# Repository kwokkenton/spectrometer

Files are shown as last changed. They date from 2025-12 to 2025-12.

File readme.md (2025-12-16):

# OpenJuice (OJ): Multispectral sensor spectrophotometer for fruit juice quality inspection

Sensor Technologies and Applications coursework 16/12/2025.

Kenton Kwok

## Installation

### Configuring the Arduino

1. Install Arduino IDE
2. Plug the Arduino into the computer via USB. Ensure that the Arduino IDE can find detect the Arduino device.
3. Ensure that SparkFun AS7343 Arduino Library is included using the Library Manager
4. Import and flash `spectrometer.ino` onto the device

This script (spectrometer.ino) is mainly based on an example script from SparkFun (see license) in the file.

### Running the main GUI

This has been tested on Python 3.13.2. The main function uses serial communications with the Arduino. Ensure that the serial monitor is off when running the Python GUI or else it won't run.

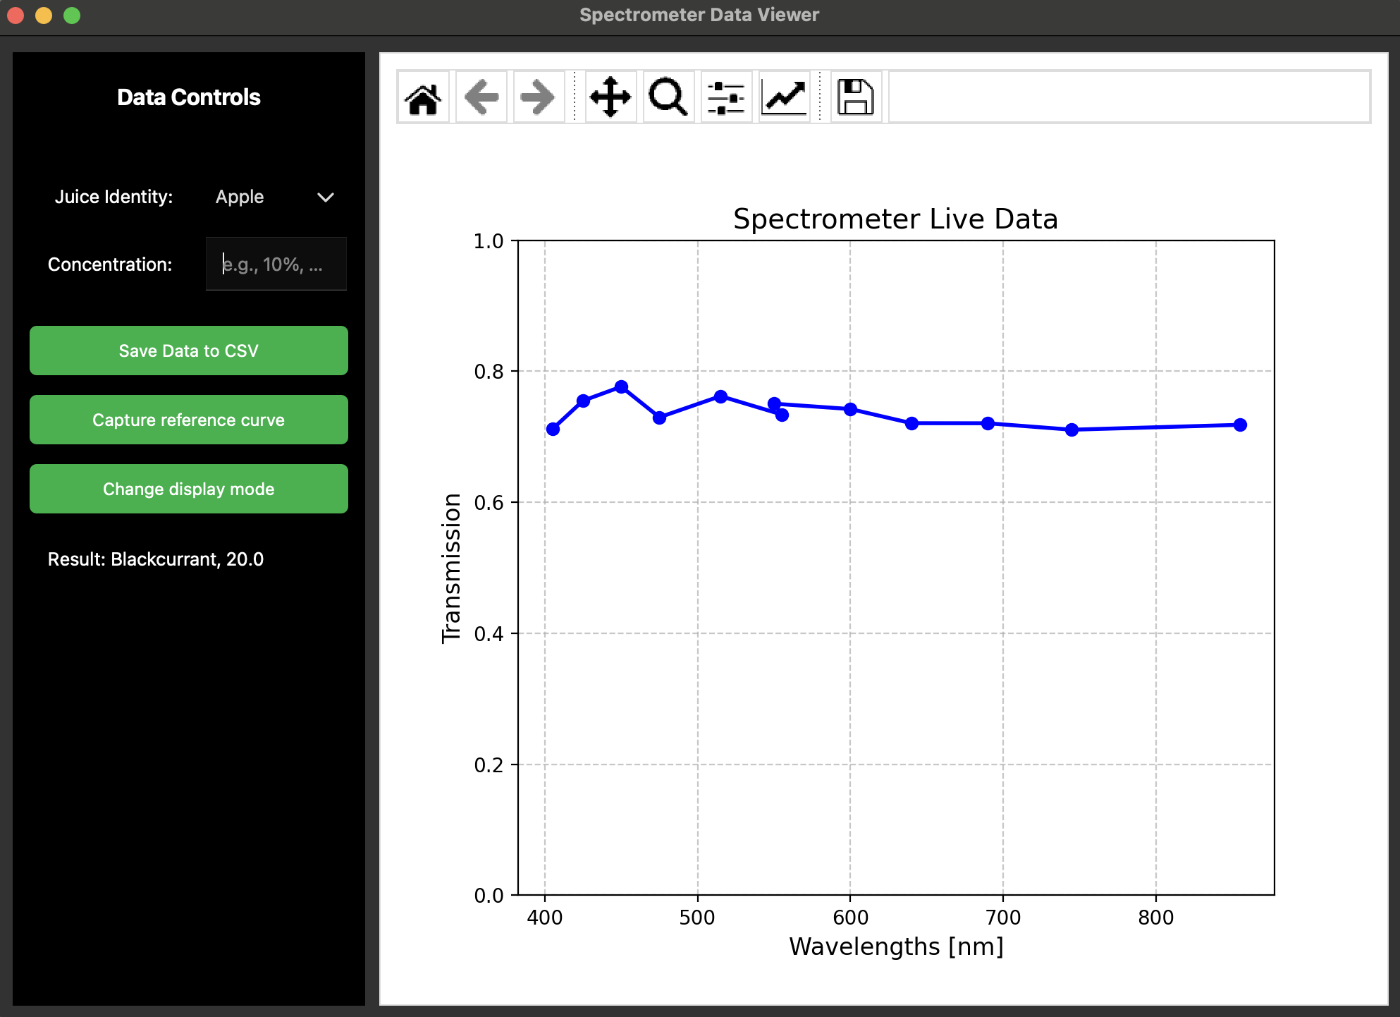
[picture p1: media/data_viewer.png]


```bash
# Installation
python3 -m venv venv
source venv/bin/activate
pip install -m requirements.txt
```

To run

```bash
python3 gui.py
```

### Creating figures

Figures are in `analysis.ipynb` for replication.

## Mechanical construction of 3D Model

Please follow construction instructions in the Appendix of the report.

## License

Copyright 2025 Kenton Kwok.

Permission is hereby granted, free of charge, to any person obtaining a copy of this software and associated documentation files (the “Software”), to deal in the Software without restriction, including without limitation the rights to use, copy, modify, merge, publish, distribute, sublicense, and/or sell copies of the Software, and to permit persons to whom the Software is furnished to do so, subject to the following conditions:

The above copyright notice and this permission notice shall be included in all copies or substantial portions of the Software.

THE SOFTWARE IS PROVIDED “AS IS”, WITHOUT WARRANTY OF ANY KIND, EXPRESS OR IMPLIED, INCLUDING BUT NOT LIMITED TO THE WARRANTIES OF MERCHANTABILITY, FITNESS FOR A PARTICULAR PURPOSE AND NONINFRINGEMENT. IN NO EVENT SHALL THE AUTHORS OR COPYRIGHT HOLDERS BE LIABLE FOR ANY CLAIM, DAMAGES OR OTHER LIABILITY, WHETHER IN AN ACTION OF CONTRACT, TORT OR OTHERWISE, ARISING FROM, OUT OF OR IN CONNECTION WITH THE SOFTWARE OR THE USE OR OTHER DEALINGS IN THE SOFTWARE.

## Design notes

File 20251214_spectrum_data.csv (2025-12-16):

F1 | F2 | FZ | F3 | F4 | F5 | FY | FXL | F6 | F7 | F8 | NIR | Juice | Concentration [%] | Timestamp
67 | 82 | 151 | 141 | 99 | 131 | 321 | 375 | 309 | 155 | 65 | 78 | Blackcurrant | 100 | 2025-12-14 10:59:36
187 | 267 | 635 | 521 | 404 | 407 | 781 | 677 | 451 | 273 | 163 | 202 | Blackcurrant | 20 | 2025-12-14 11:01:54
135 | 184 | 408 | 347 | 271 | 290 | 583 | 542 | 376 | 219 | 120 | 148 | Blackcurrant | 40 | 2025-12-14 11:02:47
97 | 129 | 266 | 230 | 174 | 202 | 438 | 446 | 330 | 181 | 89 | 110 | Blackcurrant | 60 | 2025-12-14 11:03:32
69 | 90 | 175 | 152 | 114 | 140 | 331 | 364 | 282 | 151 | 66 | 80 | Blackcurrant | 80 | 2025-12-14 11:04:13
63 | 88 | 235 | 213 | 196 | 175 | 376 | 322 | 199 | 113 | 57 | 70 | Orange | 10 | 2025-12-14 11:07:30
14 | 22 | 91 | 88 | 86 | 72 | 195 | 188 | 109 | 53 | 15 | 17 | Orange | 20 | 2025-12-14 11:08:15
1 | 4 | 23 | 23 | 35 | 27 | 89 | 85 | 48 | 21 | 2 | 2 | Orange | 40 | 2025-12-14 11:09:22
0 | 1 | 7 | 7 | 18 | 16 | 53 | 52 | 30 | 14 | 2 | 1 | Orange | 60 | 2025-12-14 11:10:12
0 | 1 | 3 | 4 | 13 | 12 | 41 | 42 | 25 | 11 | 1 | 1 | Orange | 80 | 2025-12-14 11:12:10
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

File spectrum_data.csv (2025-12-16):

F1 | F2 | FZ | F3 | F4 | F5 | FY | FXL | F6 | F7 | F8 | NIR | Juice | Concentration [%] | Timestamp
275 | 387 | 939 | 795 | 617 | 604 | 996 | 891 | 576 | 368 | 238 | 291 | Water | 100 | 2025-12-10 18:07:47
275 | 387 | 938 | 794 | 616 | 603 | 996 | 891 | 576 | 368 | 237 | 291 | Water | 100 | 2025-12-10 18:07:49
275 | 387 | 938 | 794 | 617 | 604 | 996 | 891 | 576 | 368 | 238 | 291 | Water | 100 | 2025-12-10 18:07:50
275 | 387 | 939 | 795 | 617 | 603 | 996 | 892 | 576 | 368 | 238 | 292 | Water | 100 | 2025-12-10 18:07:52
275 | 387 | 938 | 794 | 617 | 604 | 996 | 891 | 577 | 368 | 237 | 291 | Water | 100 | 2025-12-10 18:07:53
199 | 271 | 626 | 538 | 406 | 428 | 819 | 726 | 487 | 294 | 175 | 214 | Blackcurrant | 20 | 2025-12-10 18:15:01
199 | 271 | 626 | 540 | 406 | 428 | 820 | 726 | 488 | 294 | 175 | 214 | Blackcurrant | 20 | 2025-12-10 18:15:03
199 | 270 | 625 | 539 | 406 | 428 | 820 | 725 | 487 | 294 | 175 | 214 | Blackcurrant | 20 | 2025-12-10 18:15:05
199 | 270 | 624 | 537 | 406 | 427 | 819 | 723 | 487 | 294 | 175 | 214 | Blackcurrant | 20 | 2025-12-10 18:15:07
199 | 270 | 625 | 539 | 406 | 427 | 819 | 725 | 487 | 294 | 174 | 214 | Blackcurrant | 20 | 2025-12-10 18:15:08
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

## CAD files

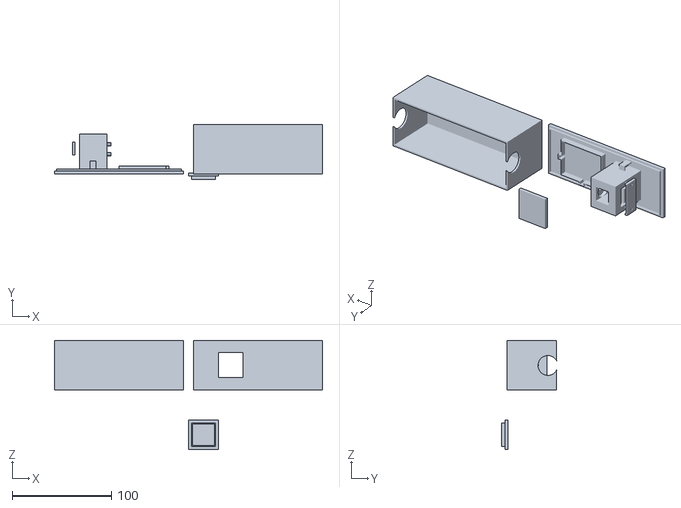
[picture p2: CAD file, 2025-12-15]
spectrometer.stl
270.0 x 55.9 x 110.0

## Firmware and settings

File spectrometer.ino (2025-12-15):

/*
  Using the AMS AS7343 Sensor.

  This example shows how to setup the AS7343 sensor with default settings and
  print out all the spectral data from the sensor.

  By: Pete Lewis
  SparkFun Electronics
  Date: 2025/04/22
  SparkFun code, firmware, and software is released under the MIT License.
    Please see LICENSE.md for further details.

  Hardware Connections:
  IoT RedBoard --> AS7331
  QWIIC --> QWIIC

  Serial.print it out at 115200 baud to serial monitor.

  Feel like supporting our work? Buy a board from SparkFun!
  https://www.sparkfun.com/products/23220
*/

#include <SparkFun_AS7343.h>

SfeAS7343ArdI2C mySensor;

uint16_t myData[ksfAS7343NumChannels]; // Array to hold spectral data
int pin = 9;

sfe_as7343_again_t gainSettings[] = {
    AGAIN_0_5,
    AGAIN_1,
    AGAIN_2,
    AGAIN_4,
    AGAIN_8,
    AGAIN_16,
    AGAIN_32,
    AGAIN_64,
    AGAIN_128,
    AGAIN_256,
    AGAIN_512,
    AGAIN_1024,
    AGAIN_2048};

// Variable to hold current user set gain index (position within the array)
int gainSettingIndex = 8; // default to 256x gain


void LEDSetup() 
{
    pinMode(pin, OUTPUT);           // set pin to input
    digitalWrite(pin, HIGH); 
}

void setup()
{   
    Serial.begin(115200);
    while (!Serial)
    {
        delay(100);
    };

    Wire.begin();

    // Initialize sensor and run default setup.
    if (mySensor.begin() == false)
    {
        Serial.println("Sensor failed to begin. Please check your wiring!");
        Serial.println("Halting...");
        while (1)
            ;
    }

    Serial.println("Sensor began.");

    // Power on the device
    if (mySensor.powerOn() == false)
    {
        Serial.println("Failed to power on the device.");
        Serial.println("Halting...");
        while (1)
            ;
    }
    Serial.println("Device powered on.");

    // Set the AutoSmux to output all 18 channels
    if (mySensor.setAutoSmux(AUTOSMUX_18_CHANNELS) == false)
    {
        Serial.println("Failed to set AutoSmux.");
        Serial.println("Halting...");
        while (1)
            ;
    }
    Serial.println("AutoSmux set to 18 channels.");

    // Enable Spectral Measurement
    if (mySensor.enableSpectralMeasurement() == false)
    {
        Serial.println("Failed to enable spectral measurement.");
        Serial.println("Halting...");
        while (1)
            ;
    }
    Serial.println("Spectral measurement enabled.");

    LEDSetup();

}

void loop()
{
    // mySensor.ledOn();
    // delay(100);

    // Read all data registers
    // if it fails, print a failure message and continue
    if (mySensor.readSpectraDataFromSensor() == false)
    {
        Serial.println("Failed to read spectral data.");
    }

    // mySensor.ledOff();

    char buffer[100];

    // fill buffer with the channel data in the correct order
    // The order is important, as the web terminal will use this order to display the bar graphs.
    // F1, F2, FZ, F3, F4, F5, FY, FXL, F6, F7, F8, VIS, NIR
    sprintf(buffer, "%d,%d,%d,%d,%d,%d,%d,%d,%d,%d,%d,%d\n",
           mySensor.getChannelData(CH_PURPLE_F1_405NM),
           mySensor.getChannelData(CH_DARK_BLUE_F2_425NM),
           mySensor.getChannelData(CH_BLUE_FZ_450NM),
           mySensor.getChannelData(CH_LIGHT_BLUE_F3_475NM),
           mySensor.getChannelData(CH_BLUE_F4_515NM),
           mySensor.getChannelData(CH_GREEN_F5_550NM),
           mySensor.getChannelData(CH_GREEN_FY_555NM),
           mySensor.getChannelData(CH_ORANGE_FXL_600NM),
           mySensor.getChannelData(CH_BROWN_F6_640NM),
           mySensor.getChannelData(CH_RED_F7_690NM),
           mySensor.getChannelData(CH_DARK_RED_F8_745NM),
        //    mySensor.getChannelData(CH_VIS_1),
           mySensor.getChannelData(CH_NIR_855NM));

    if (mySensor.setAgain(gainSettings[gainSettingIndex]) == false)
    {
        Serial.println("Failed to set gain.");
        return;
    }

    Serial.println(buffer);

    delay(500);
}

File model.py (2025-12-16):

import numpy as np
import pandas as pd
from scipy.interpolate import CubicSpline, interp1d

wavelengths_nm = np.array([405, 425, 450, 475, 515, 555, 550, 600, 640, 690, 745, 855])


class Database:
    def __init__(self, limit=0, limit_end = None):
        self.templates = []
        self.targets = []
        self.limit = limit
        self.limit_end = limit_end
    
    def add(self, x, y):
        self.templates.append(x)
        self.targets.append(y)
        return
    
    def search(self, x):
        x = x[self.limit:self.limit_end]
        return self.targets[np.argmin(np.linalg.norm(np.array(self.templates)[:,self.limit:self.limit_end]- x, axis=1))]
    
    def __len__(self):
        return len(self.targets)
    
def synthesise_absorbance(splines, c):
    return np.array([s(c) for s in splines])

def populate_db(juices, db, data, mode = 'spline'):
    for j in juices:
        splines = []
        for w in range(len(wavelengths_nm)):
            concs = data[j][0]
            pts = [i[w] for i in data[j][1]]
            if mode == 'spline':
                spline = CubicSpline(concs, pts)
            else:
                spline = interp1d(concs, pts)
            splines.append(spline)

        for idx, conc in enumerate(np.linspace(data[j][0].min(), data[j][0].max(), 21)):
            t = synthesise_absorbance(splines, conc)
            db.add(t, (j,conc))
    return db

def compute_absorbance(arr):
    return np.clip(-np.log10(arr), 0, 5)

def compute_data(df):
    df = pd.read_csv('spectrum_data.csv', delimiter=',')
    juices = list(df.Juice.unique())[1:]

    blank = df.loc[df.Juice == 'Water'].iloc[:, :12].values.mean(axis=0)
    blank_std = df.loc[df.Juice == 'Water'].iloc[:, :12].values.std(axis=0)

    data = {}

    for i, j in enumerate(juices):
        sums = []
        concentrations = []
        yerrs = []

        for c in sorted(df['Concentration [%]'].unique()):
            values = df.loc[(df.Juice == j) & (df['Concentration [%]'] == c)].iloc[:, :12].values
            if len(values) > 0:
                concentrations.append(int(c))
                mean = values.mean(axis=0)
                std = values.std(axis=0)
                mean_norm = mean/blank
                std_norm = std/blank
                yerr = np.clip(np.sqrt((0.5 / mean)**2 + (blank_std/blank)**2)/np.log(10), 0, 1)
                sums.append(mean_norm)
                yerrs.append(yerr)

        concentrations = np.array(concentrations)
        yerrs = np.array(yerrs)

        absorbances = compute_absorbance(sums)
        data[j] = concentrations, absorbances, yerrs
    return juices, data

def make_db():
    df = pd.read_csv('spectrum_data.csv', delimiter=',')
    db = Database(limit=2, limit_end=-1)
    juices, data = compute_data(df)
    db = populate_db(juices, db, data)  
    return db
